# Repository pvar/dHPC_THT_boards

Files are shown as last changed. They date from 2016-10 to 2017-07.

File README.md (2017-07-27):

# dHPC

## What is this?

dHPC stands for deltaHacker PC and it's a small **home-brew** computer. It's not only small
in size, but in performance too! The capabilities of this tiny system resemble those of the 80's
home computers. It was built as a project for [deltaHacker magazine][delta], an ethical hacking
magazine, that occasionally hosts articles about electronics.

## What can I do with it?

The computer.* files in this repository were created with [Eagle][eagle], a popular choice for
PCB design among makers and students. In order to view the schematics or the PCB, you need to
download the free version of the program. Alternatively, you could use the on-line viewer that
many board manufacturers facilitate on their websites. You can find a noteworthy viewer of this
kind at [EuroCircuits][euro].

## Is it possible to make one?

Of course it is! Keep in mind, though, that the three microcontrollers which comprise the system
need to be "burnt" with the appropriate firmware. This means you'll need a programmer for AVR
microcontrollers, such as [this one][avrisp]. If you have no idea what a programmer is, you'll
need the help of some electronics tinkerer/hobbyist/engineer.

## I'm good to go! Where is the firmware?

You can find the source code for the firmware of each sub-system in the relevant repository:

* [For the CPU][cpu] (source code in C)
* [For the GPU][gpu] (source code in ASM and the "compiled" HEX)
* [For the APU][apu] (source code in ASM and the "compiled" HEX)

[delta]:    http://deltahacker.gr                       "ethical hacking magazine"
[eagle]:    http://cadsoft.io                           "Eagle PCB design"
[euro]:     http://www.eurocircuits.com                 "EuroCircuit PCB services"
[avrisp]:   http://www.atmel.com/tools/AVRISPMKII.aspx  "AVR ISP programmer homepage"
[cpu]:      https://github.com/pvar/nstBASIC            "firmware for the main processor"
[gpu]:      https://github.com/pvar/dhpc_gpu_firmware   "firmware for the graphics processor"
[apu]:      https://github.com/pvar/dhpc_apu_firmware   "firmware for the sound processor"

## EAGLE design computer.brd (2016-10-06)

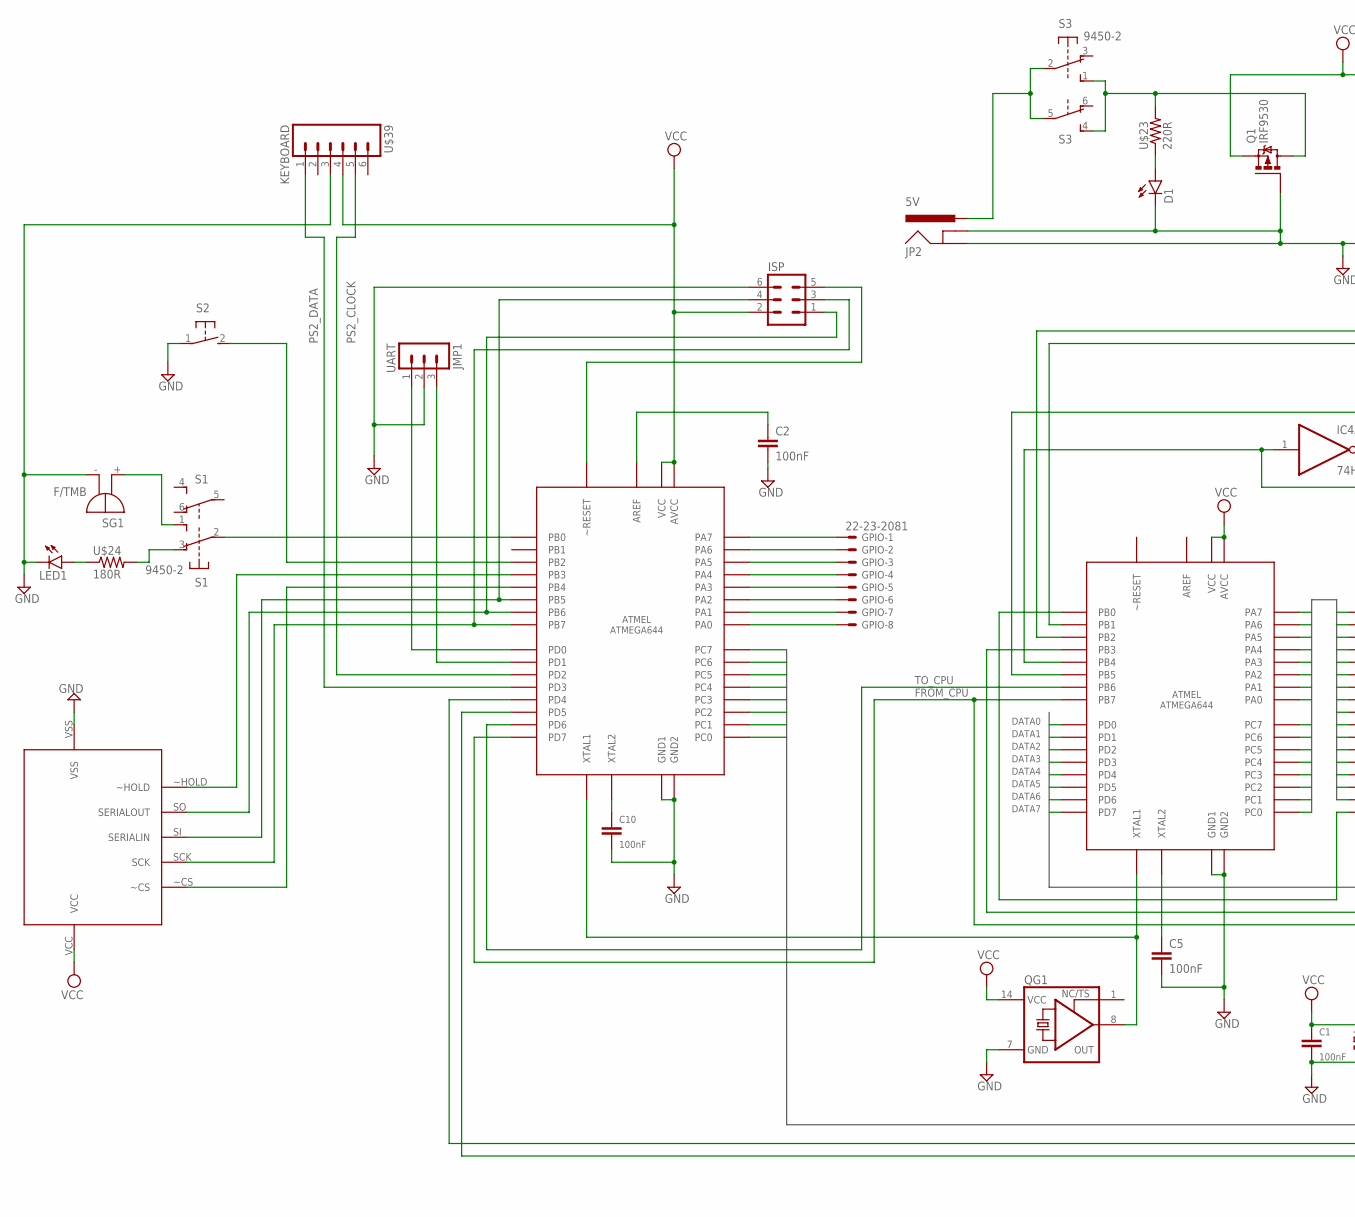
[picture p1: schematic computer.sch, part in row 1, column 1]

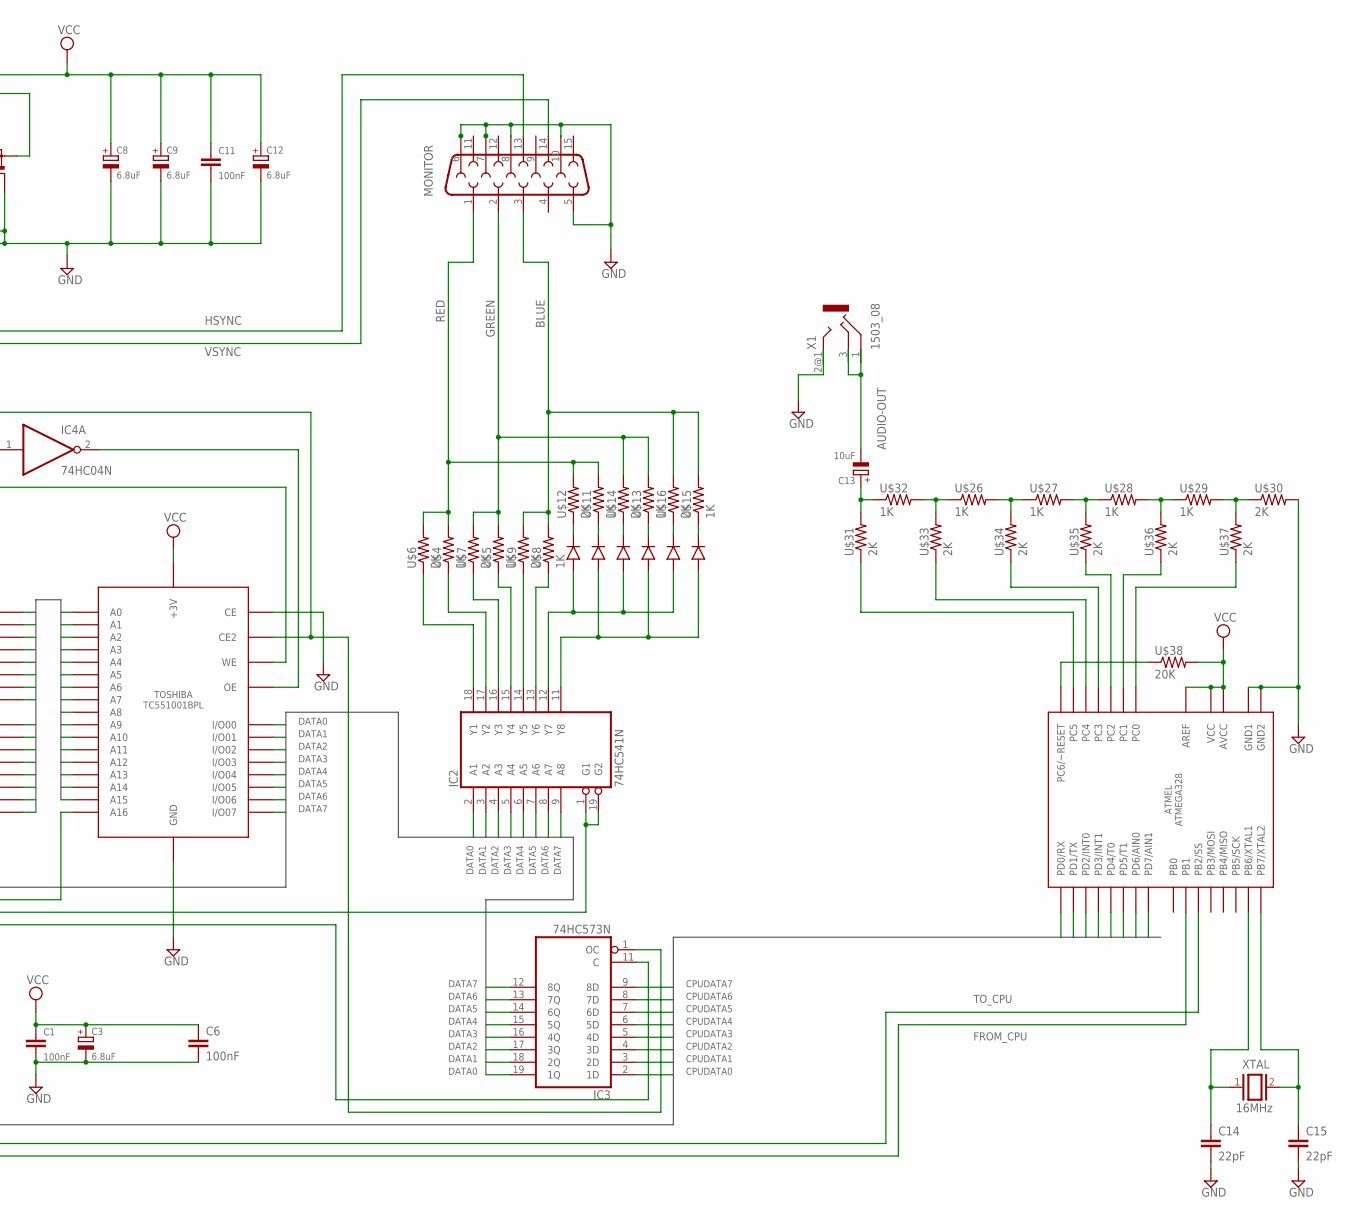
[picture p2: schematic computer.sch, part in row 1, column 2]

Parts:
C1, C10, C11: 100nF; C5B2.5
C2, C5, C6: 100nF; CAP-PTH-SMALLEZ
C3, C8, C9, C12: 6.8uF; E5-5
C13: 10uF; E5-5
C14, C15: 22pF; CAP-PTH-SMALLEZ
D1: LED5MM
GPIO: 22-23-2081
IC2: 74HC541N; DIL20
IC3: 74HC573N; DIL20
IC4: 74HC04N; DIL14
ISP: ML6
JMP1: UART; MA03-1
JP2: 5V; POWER_JACK_PTH
LED1: LED5MM
Q1: IRF9530; TO220BV
QG1: XO-14; DIL14S
S1, S3: 9450-2
S2: 31-XX; B3F-31XX
SG1: F/TMB
U$1, U$2: ATMEGA644
U$3: TC551001BPL
U$4, U$5, U$8, U$11, U$13, U$15, U$26, U$27, U$28, U$29, U$32: 1K; AXIAL-0.3EZ
U$6, U$7, U$9, U$12, U$14, U$16, U$30, U$31, U$33, U$34, U$35, U$36, U$37: 2K; AXIAL-0.3EZ
U$10: 23LC1024
U$17, U$18, U$19, U$20, U$21, U$22: DIODE
U$23: 220R; AXIAL-0.3EZ
U$24: 180R; AXIAL-0.3EZ
U$25: ATMEGA328
U$38: 20K; AXIAL-0.3EZ
U$39: KEYBOARD; MINI-DIN6
U$40: MONITOR; DB15
X1: 1503_08
XTAL: 16MHz; QS

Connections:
ADDRESS0: U$2.PC0, U$3.A0
ADDRESS1: U$2.PC1, U$3.A1
ADDRESS2: U$2.PC2, U$3.A2
ADDRESS3: U$2.PC3, U$3.A3
ADDRESS4: U$2.PC4, U$3.A4
ADDRESS5: U$2.PC5, U$3.A5
ADDRESS6: U$2.PC6, U$3.A6
ADDRESS7: U$2.PC7, U$3.A7
ADDRESS8: U$2.PA0, U$3.A8
ADDRESS9: U$2.PA1, U$3.A9
ADDRESS10: U$2.PA2, U$3.A10
ADDRESS11: U$2.PA3, U$3.A11
ADDRESS12: U$2.PA4, U$3.A12
ADDRESS13: U$2.PA5, U$3.A13
ADDRESS14: U$2.PA6, U$3.A14
ADDRESS15: U$2.PA7, U$3.A15
AUDIO-OUT: C13.-, X1.1, X1.3
BLUE: U$8.P$2 (2), U$9.P$2 (2), U$15.P$2 (2), U$16.P$2 (2), U$40.3
CPUDATA0: IC3.2 (1D), U$1.PC0, U$25.PD0/RX
CPUDATA1: IC3.3 (2D), U$1.PC1, U$25.PD1/TX
CPUDATA2: IC3.4 (3D), U$1.PC2, U$25.PD2/INT0
CPUDATA3: IC3.5 (4D), U$1.PC3, U$25.PD3/INT1
CPUDATA4: IC3.6 (5D), U$1.PC4, U$25.PD4/T0
CPUDATA5: IC3.7 (6D), U$1.PC5, U$25.PD5 (PD5/T1)
CPUDATA6: IC3.8 (7D), U$1.PC6, U$25.PD6 (PD6/AIN0)
CPUDATA7: IC3.9 (8D), U$1.PC7, U$25.PD7 (PD7/AIN1)
DATA0: IC2.2 (A1), IC3.19 (1Q), U$2.PD0, U$3.I/O1 (I/O00)
DATA1: IC2.3 (A2), IC3.18 (2Q), U$2.PD1, U$3.I/O2 (I/O01)
DATA2: IC2.4 (A3), IC3.17 (3Q), U$2.PD2, U$3.I/O3 (I/O02)
DATA3: IC2.5 (A4), IC3.16 (4Q), U$2.PD3, U$3.I/O4 (I/O03)
DATA4: IC2.6 (A5), IC3.15 (5Q), U$2.PD4, U$3.I/O5 (I/O04)
DATA5: IC2.7 (A6), IC3.14 (6Q), U$2.PD5, U$3.I/O6 (I/O05)
DATA6: IC2.8 (A7), IC3.13 (7Q), U$2.PD6, U$3.I/O7 (I/O06)
DATA7: IC2.9 (A8), IC3.12 (8Q), U$2.PD7, U$3.I/O8 (I/O07)
FROM_CPU: IC3.11 (C), U$1.PD5, U$1.PD7, U$2.PB7, U$25.PB1
GND: C1.2, C2.2, C3.-, C5.2, C6.2, C8.-, C9.-, C10.2, C11.2, C12.-, C14.2, C15.2, D1.K (C), IC2.10 (GND), IC3.10 (GND), IC4.7 (GND), ISP.6, JMP1.2, JP2.GND, JP2.GNDBREAK, LED1.K (C), Q1.G, QG1.7 (GND), S2.1, SG1.-, U$1.GND (GND1), U$1.GND.1 (GND2), U$2.GND (GND1), U$2.GND.1 (GND2), U$3.GND, U$3.~CE1 (CE), U$10.VSS, U$25.GND (GND1), U$25.GND1 (GND2), U$30.P$2 (2), U$39.3, U$40.5, U$40.6, U$40.7, U$40.8, U$40.10, X1.2@1 (2), X1.2@2 (2)
GREEN: U$5.P$2 (2), U$7.P$2 (2), U$13.P$2 (2), U$14.P$2 (2), U$40.2
HSYNC: U$2.PB2, U$40.13
unnamed: QG1.8 (OUT), U$1.XTAL1, U$2.XTAL1
unnamed: U$12.P$1 (1), U$17.CA (CATHODE)
unnamed: IC4.2 (O), U$3.~OE (OE)
unnamed: GPIO.1, U$1.PA7
unnamed: U$2.PB0, U$3.A16
unnamed: IC2.1 (G1), IC2.19 (G2), U$2.PB3
unnamed: C5.1, U$2.XTAL2
unnamed: IC3.1 (OC), U$2.PB5, U$3.CE2
unnamed: C13.+, U$31.P$2 (2), U$32.P$1 (1)
unnamed: IC4.1 (I), U$2.PB4, U$3.R/W (WE)
unnamed: C10.1, U$1.XTAL2
unnamed: U$11.P$1 (1), U$18.CA (CATHODE)
unnamed: U$14.P$1 (1), U$19.CA (CATHODE)
unnamed: U$13.P$1 (1), U$20.CA (CATHODE)
unnamed: U$16.P$1 (1), U$21.CA (CATHODE)
unnamed: U$15.P$1 (1), U$22.CA (CATHODE)
unnamed: JP2.PWR, S3.2, S3.5
unnamed: S1.1 (S), SG1.+
unnamed: S1.3 (O), U$24.P$2 (2)
unnamed: LED1.A, U$24.P$1 (1)
unnamed: S1.2, U$1.PB0
unnamed: JMP1.1, U$1.PD0
unnamed: IC2.18 (Y1), U$6.P$1 (1)
unnamed: IC2.17 (Y2), U$4.P$1 (1)
unnamed: IC2.16 (Y3), U$7.P$1 (1)
unnamed: IC2.15 (Y4), U$5.P$1 (1)
unnamed: IC2.14 (Y5), U$9.P$1 (1)
unnamed: IC2.13 (Y6), U$8.P$1 (1)
unnamed: IC2.12 (Y7), U$17.AN (ANODE), U$19.AN (ANODE), U$21.AN (ANODE)
unnamed: IC2.11 (Y8), U$18.AN (ANODE), U$20.AN (ANODE), U$22.AN (ANODE)
unnamed: U$26.P$1 (1), U$32.P$2 (2), U$33.P$2 (2)
unnamed: U$26.P$2 (2), U$27.P$1 (1), U$34.P$2 (2)
unnamed: U$27.P$2 (2), U$28.P$1 (1), U$35.P$2 (2)
unnamed: U$28.P$2 (2), U$29.P$1 (1), U$36.P$2 (2)
unnamed: U$29.P$2 (2), U$30.P$1 (1), U$37.P$2 (2)
unnamed: U$25.PC5/ADC5 (PC5), U$31.P$1 (1)
unnamed: U$25.PC4/ADC4 (PC4), U$33.P$1 (1)
unnamed: U$25.PC3/ADC3 (PC3), U$34.P$1 (1)
unnamed: U$25.PC2/ADC2 (PC2), U$35.P$1 (1)
unnamed: U$25.PC1/ADC1 (PC1), U$36.P$1 (1)
unnamed: U$25.PC0/ADC0 (PC0), U$37.P$1 (1)
unnamed: U$25.PC6/RESET (PC6/~RESET), U$38.P$1 (1)
unnamed: C14.1, U$25.PB6 (PB6/XTAL1), XTAL.1
unnamed: C15.1, U$25.PB7 (PB7/XTAL2), XTAL.2
unnamed: C2.1, U$1.AREF
unnamed: JMP1.3, U$1.PD1
unnamed: ISP.3, U$1.PB7, U$10.SCK
unnamed: S2.2 (S), U$1.PB2
unnamed: ISP.1, U$1.PB6, U$10.SO (SERIALOUT)
unnamed: ISP.4, U$1.PB5, U$10.SI (SERIALIN)
unnamed: U$1.PB4, U$10.~CS
unnamed: U$1.PB3, U$10.~HOLD
unnamed: GPIO.2, U$1.PA6
unnamed: GPIO.3, U$1.PA5
unnamed: GPIO.4, U$1.PA4
unnamed: GPIO.5, U$1.PA3
unnamed: GPIO.6, U$1.PA2
unnamed: GPIO.7, U$1.PA1
unnamed: GPIO.8, U$1.PA0
unnamed: ISP.5, U$1.~RESET
unnamed: Q1.D, S3.1 (S), S3.4 (S), U$23.P$2 (2)
unnamed: D1.A, U$23.P$1 (1)
PS2_CLOCK: U$1.PD2, U$39.5
PS2_DATA: U$1.PD3, U$39.1
RED: U$4.P$2 (2), U$6.P$2 (2), U$11.P$2 (2), U$12.P$2 (2), U$40.1
TO_CPU: U$1.PD4, U$1.PD6, U$2.PB6, U$25.PB2/SS
VCC: C1.1, C3.+, C6.1, C8.+, C9.+, C11.1, C12.+, IC2.20 (VCC), IC3.20 (VCC), IC4.14 (VCC), ISP.2, Q1.S, QG1.14 (VCC), U$1.AVCC, U$1.VCC, U$2.AVCC, U$2.VCC, U$3.VDD (+3V), U$10.VCC, U$25.AREF, U$25.AVCC, U$25.VCC, U$38.P$2 (2), U$39.4
VSYNC: U$2.PB1, U$40.14

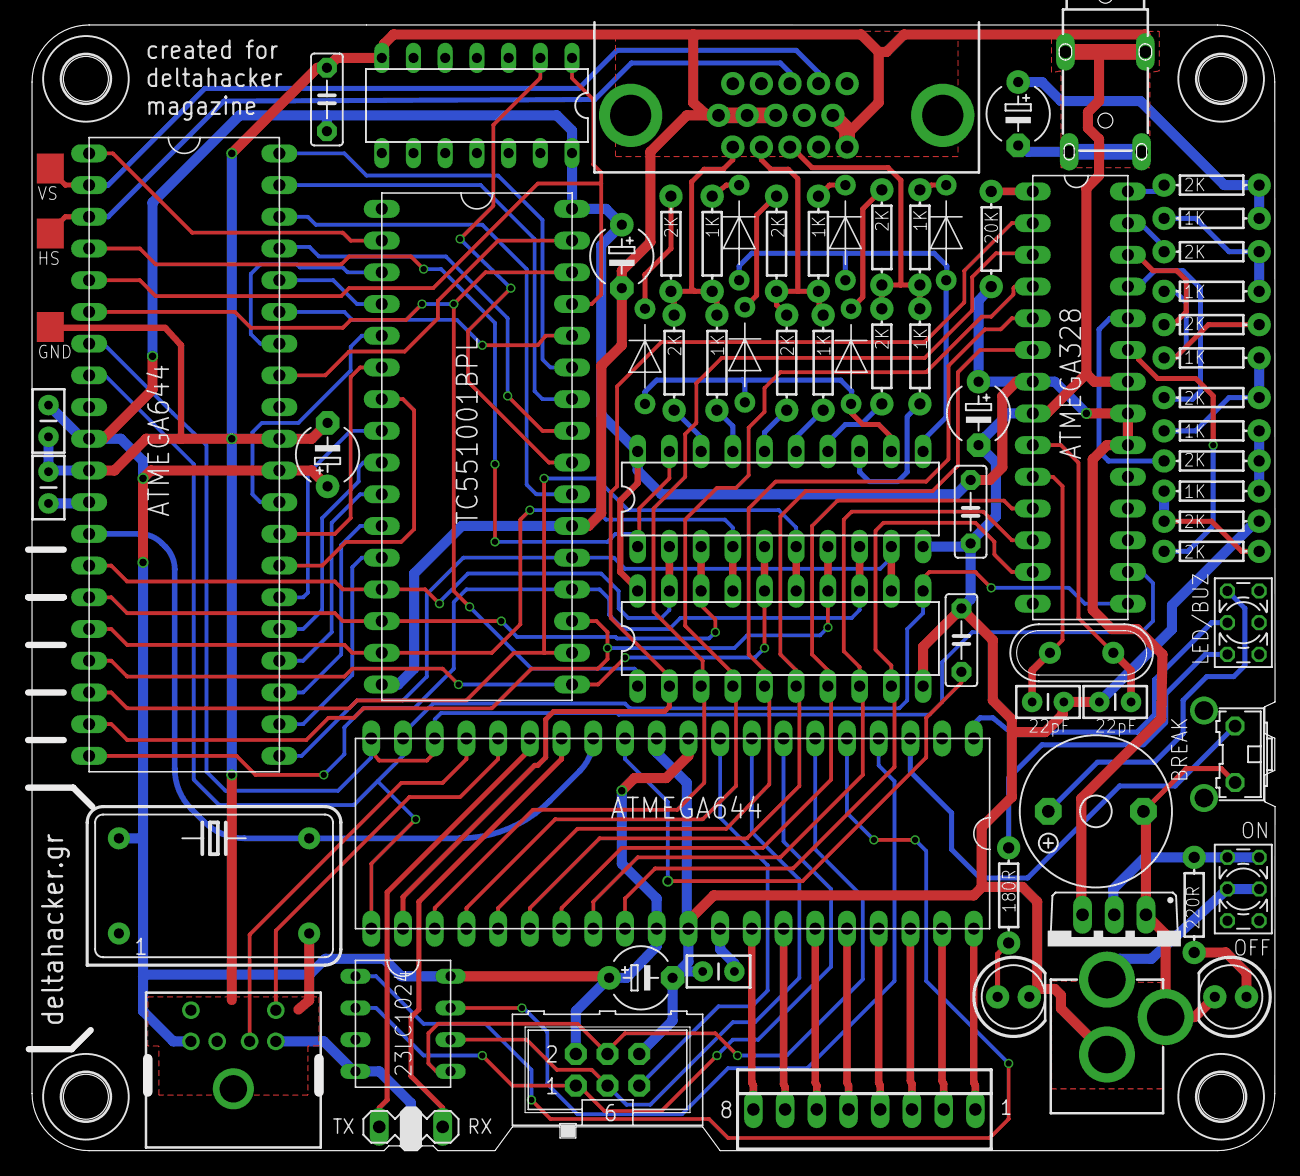
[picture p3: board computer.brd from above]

Board: 2 copper layers, 99.6 x 90.2 mm, 74 parts (0 on the bottom side), 106 nets.

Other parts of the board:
H1, H2, H4, H5: MOUNT-HOLE3.0; 3,6

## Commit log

2016-09-13 initial commit: hbpc schematic and pcb
    [full computer.brd, full computer.sch]
2016-09-13 moved PS2 to rear side and BREAK button to front side, the board is now a bit smaller
    [full computer.brd, full computer.sch]
2016-09-17 added SD card holder & rounded corners
    [full computer.brd, full computer.sch]
2016-09-21 removed SD card holder & added external SRAM & reverse voltage protection
    [full computer.brd, full computer.sch]
2016-10-03 board completely redesigned!
    [full computer.brd, full computer.sch]
2016-10-03 added test pads for H anv V sync signals
    [full computer.brd]
2016-10-03 added deltahacker name, decorative cuts and contour curves
    [full computer.brd]
2016-10-03 added more decorative cuts, open hardware logo and some text
    [full computer.brd]
2016-10-03 thiner and shorter traces for clock signals, better position for GPIO and SERIAL, schematic clean up
    [full computer.brd, full computer.sch]
2016-10-03 added README and LICENSE
    [computer.brd, computer.sch]
2016-10-06 minor modifications (mainly to satisfy my OCD)
    [computer.brd]

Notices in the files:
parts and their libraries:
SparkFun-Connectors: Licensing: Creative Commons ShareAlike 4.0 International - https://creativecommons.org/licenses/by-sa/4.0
